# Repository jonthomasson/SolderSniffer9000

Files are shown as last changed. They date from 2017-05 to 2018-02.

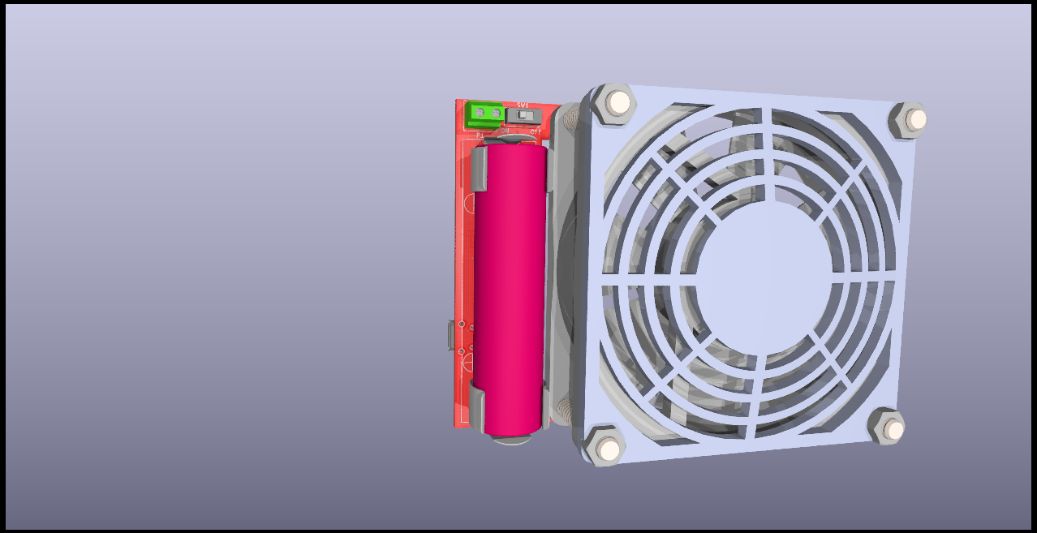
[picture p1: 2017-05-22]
rev1.a/SolderSniffer9000_3d_back.png

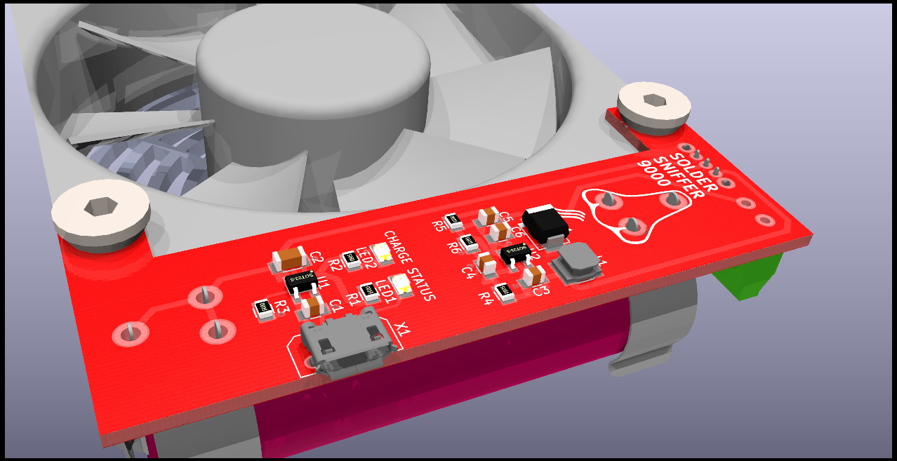
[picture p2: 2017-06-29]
rev1.a/SolderSniffer9000b.png

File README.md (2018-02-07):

# SolderSniffer9000
A DIY Solder Fume Extractor for 80mm Fan with built in battery charger.

It chops, it dices, it sucks, it blows, it's the Solder Sniffer 9000! After a recent move I was in need of a more portable solder fume extractor. Previously I was using a PC PSU hooked up to a small 80mm fan to suck away solder fumes. I thought it would be neat to make a portable sucker that could be recharged with the millions of micro USB cables I have lying around. Thus the Solder Sniffer 9000 was born! This project is built around an 80mm PSU fan. I chose this type and size fan because that's what I have laying around. I figured it'd be great if I could recycle some of these fans. The main PCB attaches to one side of the fan, via the fan mounting holes. For power I'm using a protected 18650 lithium cell. I'm using the Microchip MCP73831 charge controller to charge the battery via the Micro USB port. The battery is then boosted to the 12 volts required by the fan through use of the Semtech SC4503 step up regulator.
![enter image description here](https://lh3.googleusercontent.com/lAs5yyoZNqOFHvuRhlynxwo_R--8PWqJcgd_jjI6EHcwee4sk6s7vFg0BtDzGmjtqx0Ff0_K_e3mD94I6FwvLRuabP4b_9Osu1a5uzanZ7PESfyJPfpcDF5x4c6m_dsZqu9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)

![enter image description here](https://lh3.googleusercontent.com/34mNDDMhwQWCEcVDpiyjnw0Z-S3oCal-eQXqZIbWolDbLpy-xn97MdiaS-pX-pZ9BGYoCawT2w7hVak32vGW6cuKDikLCVMxaWiUwZszsmvlJUHRNDMsvFF96Da90ZJn-Jc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)

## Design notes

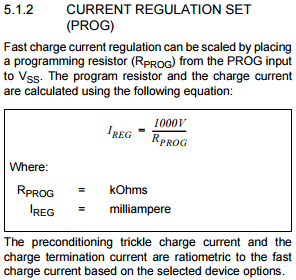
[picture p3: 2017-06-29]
rev1.a/mcp73831_currentreg.PNG

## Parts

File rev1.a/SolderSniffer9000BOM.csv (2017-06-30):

Digi-Key Part Number | Manufacturer | Manufacturer Part Number | Customer Reference | Quantity 1 | Quantity 2 | Quantity 3 | Mfg Std Lead Time | Description | Comments | RoHS Status | Lead Free Status | REACH Status
VS-10BQ015-M3/5BTGICT-ND | VISHAY SEMICONDUCTOR DIODES DIVISION (VA) | VS-10BQ015-M3/5BT | D1 | 1 | 0 | 0 | 11 Weeks | DIODE SCHOTTKY 15V 1A DO214AA | Alternate Packaging Exists | RoHS Compliant | Lead free | Unaffected Jan-2017
SC4503TSKCT-ND | SEMTECH CORPORATION (VA) | SC4503TSKTRT | U2 | 1 | 0 | 0 | 6 Weeks | IC REG BOOST ADJ 1.4A TSOT23-5 | Alternate Packaging Exists | RoHS Compliant | Lead free | Not Available
MCP73831T-2ACI/OTCT-ND | MICROCHIP TECHNOLOGY (VA) | MCP73831T-2ACI/OT | U1 | 1 | 0 | 0 | 6 Weeks | IC CONTROLLR LI-ION 4.2V SOT23-5 | Alternate Packaging Exists | RoHS Compliant | Lead free | Unaffected Jan-2017
SRN4018-2R7MCT-ND | BOURNS INC (VA) | SRN4018-2R7M | L1 | 1 | 0 | 0 | 28 Weeks | FIXED IND 2.7UH 2.3A 52 MOHM SMD | Alternate Packaging Exists | RoHS Compliant | Lead free | Unaffected Jan-2017
36-54-ND | KEYSTONE ELECTRONICS | 54 | BT1 | 2 | 0 | 0 | 6 Weeks | BATTERY CLIP 18MM 18650 CELL |  | RoHS Compliant | Lead free | Unaffected Jan-2017
ED2740-ND | ON SHORE TECHNOLOGY INC | OSTTE020104 | P1 | 1 | 0 | 0 | 10 Weeks | TERMINAL BLOCK 3.5MM 2POS PCB |  | RoHS Compliant | Lead free | Unaffected Jun-2016
CKN10397-ND | C&K | SS-12D07-VG 4 NS GA PA | SW1 | 1 | 0 | 0 | 6 Weeks | SWITCH SLIDE SPDT 300MA 30V |  | RoHS Compliant | Lead free | Unaffected Jan-2017
732-4984-1-ND | WURTH ELECTRONICS INC (VA) | 150080RS75000 | LED1 | 1 | 0 | 0 | 10 Weeks | LED RED CLEAR 0805 SMD | Alternate Packaging Exists | RoHS Compliant | Lead free | Unaffected Jun-2016
732-4986-1-ND | WURTH ELECTRONICS INC (VA) | 150080VS75000 | LED2 | 1 | 0 | 0 | 10 Weeks | LED GREEN CLEAR 0805 SMD | Alternate Packaging Exists | RoHS Compliant | Lead free | Unaffected Jun-2016
1276-2969-1-ND | SAMSUNG ELECTRO-MECHANICS AMERICA, INC (VA) | CL21B475KAFNNNE | C1, C6 | 2 | 0 | 0 | 12 Weeks | CAP CER 4.7UF 25V X7R 0805 | Alternate Packaging Exists | RoHS Compliant | Lead free | Unaffected Jan-2017
1276-1804-1-ND | SAMSUNG ELECTRO-MECHANICS AMERICA, INC (VA) | CL31B106KAHNNNE | C2 | 1 | 0 | 0 | 12 Weeks | CAP CER 10UF 25V X7R 1206 | Alternate Packaging Exists | RoHS Compliant | Lead free | Unaffected Jan-2017
1276-1162-1-ND | SAMSUNG ELECTRO-MECHANICS AMERICA, INC (VA) | CL21B225KOFNNNE | C3 | 1 | 0 | 0 | 12 Weeks | CAP CER 2.2UF 16V X7R 0805 | Alternate Packaging Exists | RoHS Compliant | Lead free | Unaffected Jan-2017
1276-1302-1-ND | SAMSUNG ELECTRO-MECHANICS AMERICA, INC (VA) | CL21C2R2CBANNNC | C5 | 1 | 0 | 0 | 12 Weeks | CAP CER 2.2PF 50V C0G/NP0 0805 | Alternate Packaging Exists | RoHS Compliant | Lead free | Unaffected Jan-2017
RMCF0805JT470RCT-ND | STACKPOLE ELECTRONICS INC (VA) | RMCF0805JT470R | R1, R2 | 2 | 0 | 0 | 12 Weeks | RES SMD 470 OHM 5% 1/8W 0805 | Alternate Packaging Exists | RoHS Compliant | Lead free | Unaffected Jan-2017
P2.00KCCT-ND | PANASONIC ELECTRONIC COMPONENTS (VA) | ERJ-6ENF2001V | R3 | 1 | 0 | 0 | 41 Weeks | RES SMD 2K OHM 1% 1/8W 0805 | Alternate Packaging Exists | RoHS Compliant | Lead free | Unaffected Jan-2017
311-15.0KCRCT-ND | YAGEO (VA) | RC0805FR-0715KL | R4 | 1 | 0 | 0 | 22 Weeks | RES SMD 15K OHM 1% 1/8W 0805 | Alternate Packaging Exists | RoHS Compliant | Lead free | Unaffected Jan-2017
311-866KCRCT-ND | YAGEO (VA) | RC0805FR-07866KL | R5 | 1 | 0 | 0 | 22 Weeks | RES SMD 866K OHM 1% 1/8W 0805 | Alternate Packaging Exists | RoHS Compliant | Lead free | Unaffected Jan-2017
311-100KCRCT-ND | YAGEO (VA) | RC0805FR-07100KL | R6 | 1 | 0 | 0 | 22 Weeks | RES SMD 100K OHM 1% 1/8W 0805 | Alternate Packaging Exists | RoHS Compliant | Lead free | Unaffected Jan-2017
1276-2536-1-ND | SAMSUNG ELECTRO-MECHANICS AMERICA, INC (VA) | CL21B563KBCNNNC | C4 | 1 | 0 | 0 | 12 Weeks | CAP CER 0.056UF 50V X7R 0805 | Alternate Packaging Exists | RoHS Compliant | Lead free | Unaffected Jan-2017
609-4618-1-ND | AMPHENOL FCI (VA) | 10118194-0001LF | X1 | 1 | 0 | 0 | 12 Weeks | CONN USB MICRO B RECPT SMT R/A | Alternate Packaging Exists | RoHS Compliant | Lead free | Not Available

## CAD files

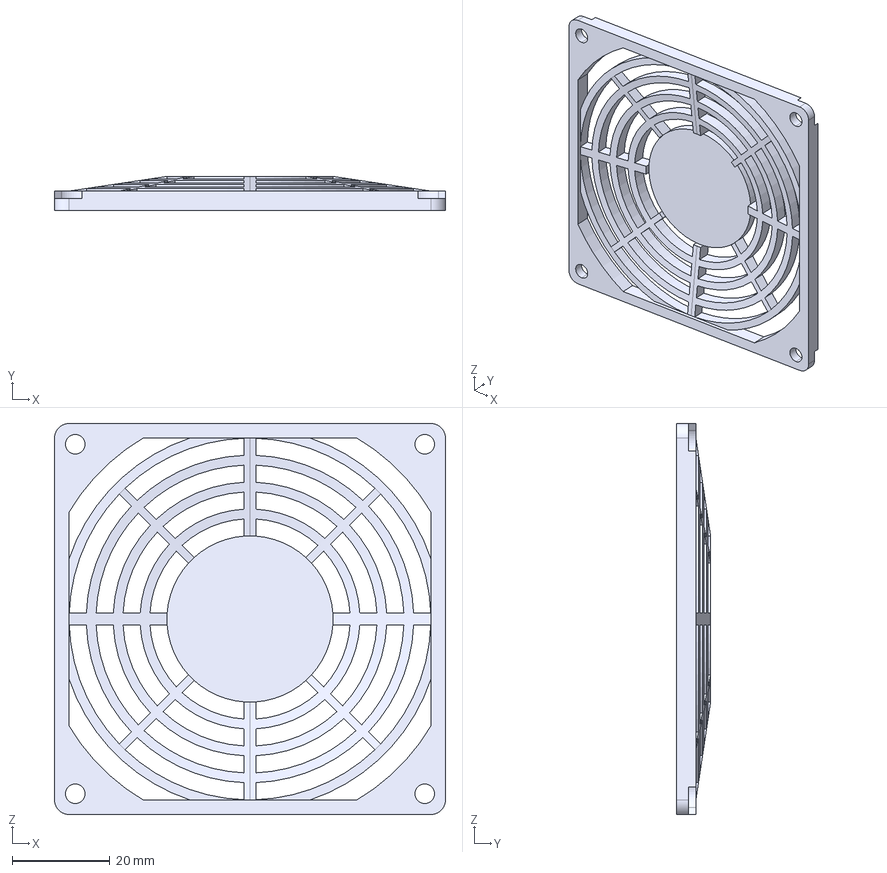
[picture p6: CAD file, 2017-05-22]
rev1.a/3dmodels/80MM_Fan_Filter.step
80.0 x 7.00 x 80.0 mm

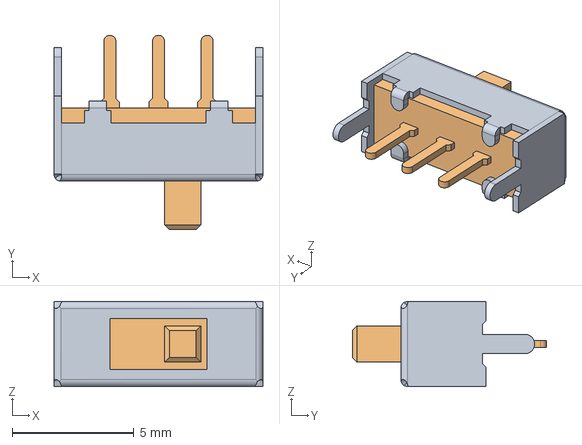
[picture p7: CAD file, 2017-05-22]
rev1.a/3dmodels/Switches_C&K_SS_12D07.step
8.60 x 8.00 x 3.50 mm

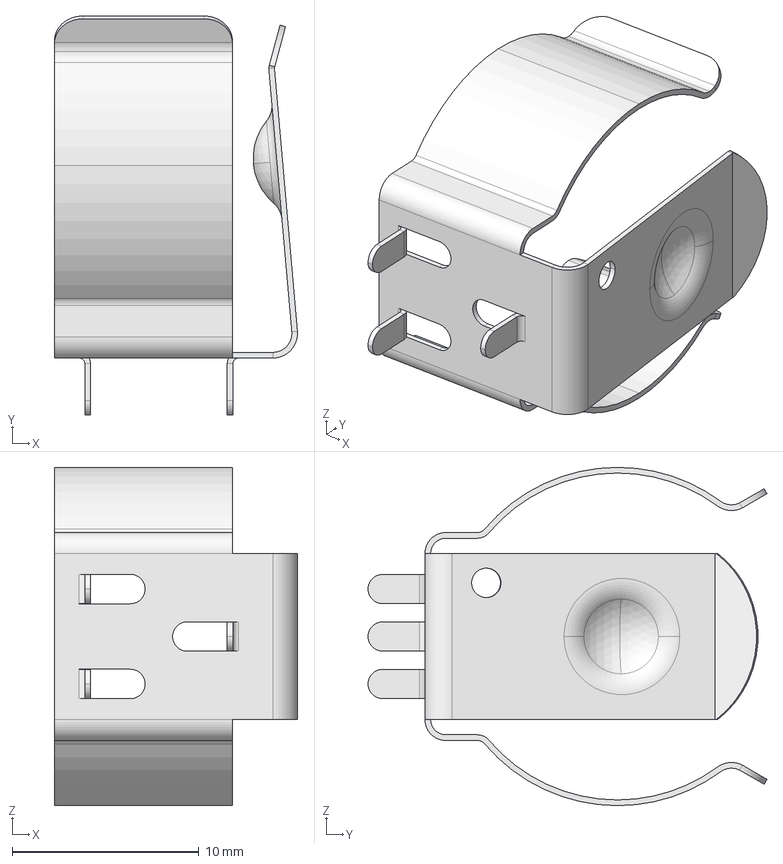
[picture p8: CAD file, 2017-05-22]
rev1.a/3dmodels/Batteries_Keystone_54.step
13.0 x 21.4 x 18.1 mm

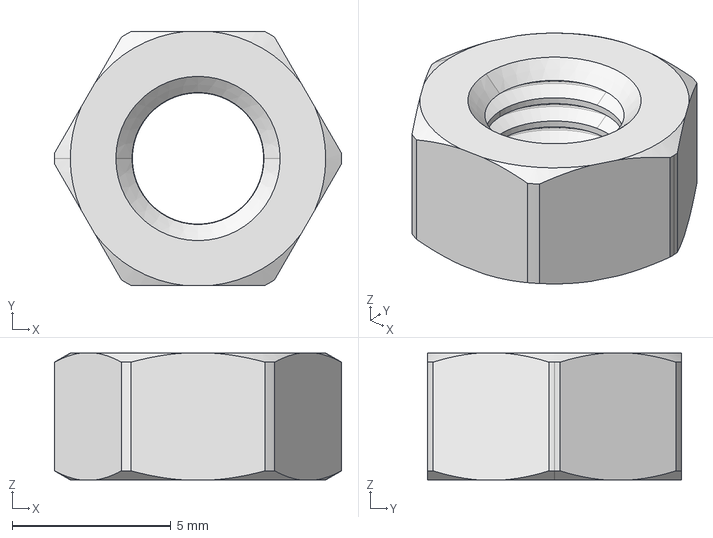
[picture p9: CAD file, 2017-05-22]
rev1.a/3dmodels/Nuts_M5.step
9.04 x 8.00 x 4.00 mm

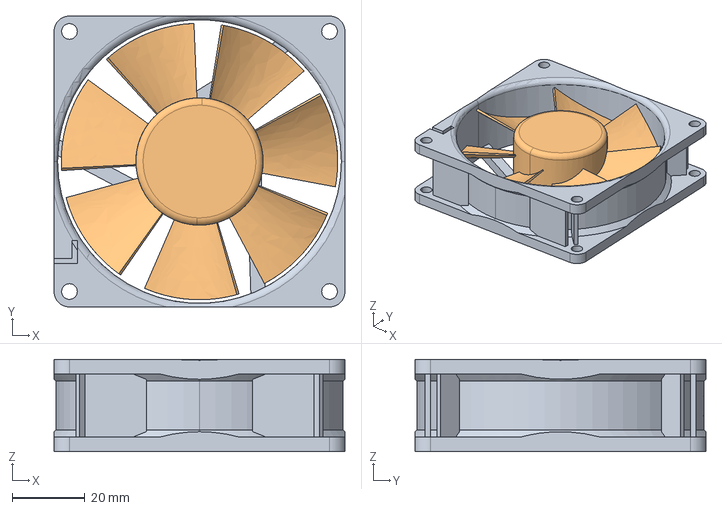
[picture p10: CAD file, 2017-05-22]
rev1.a/3dmodels/Motor_Fan.step
80.0 x 80.0 x 25.4 mm

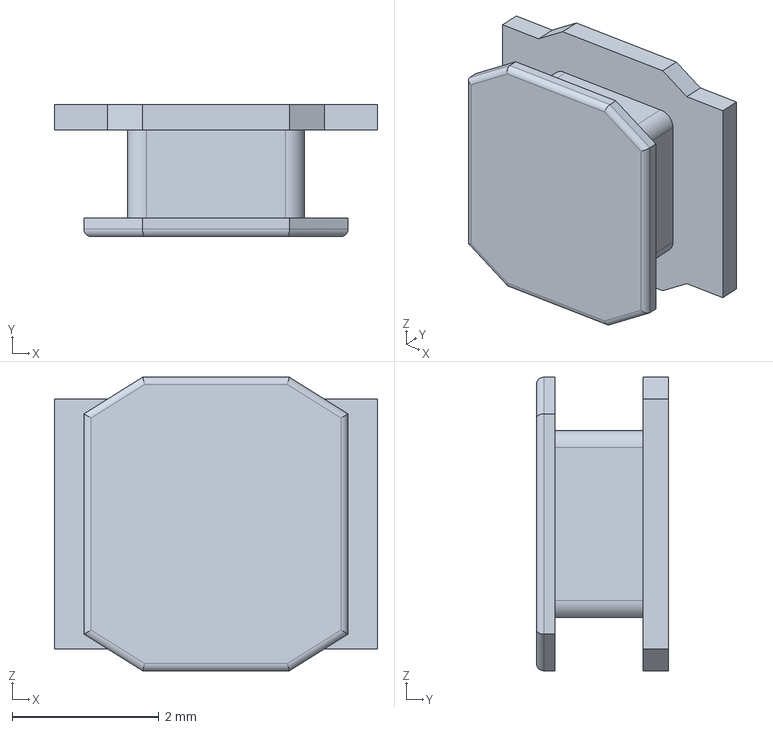
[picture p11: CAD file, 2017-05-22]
rev1.a/3dmodels/srn4018.stp
4.40 x 1.80 x 4.00 mm

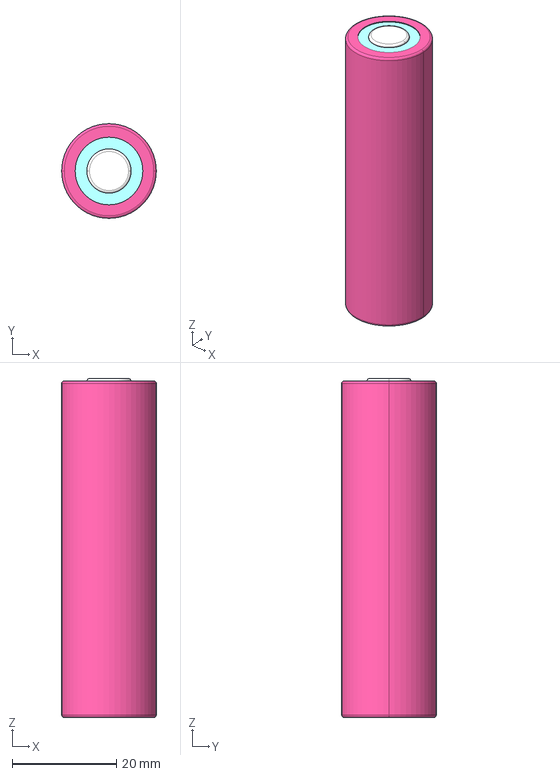
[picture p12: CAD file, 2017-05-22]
rev1.a/3dmodels/Battery_18650_c.step
18.2 x 18.2 x 65.2 mm

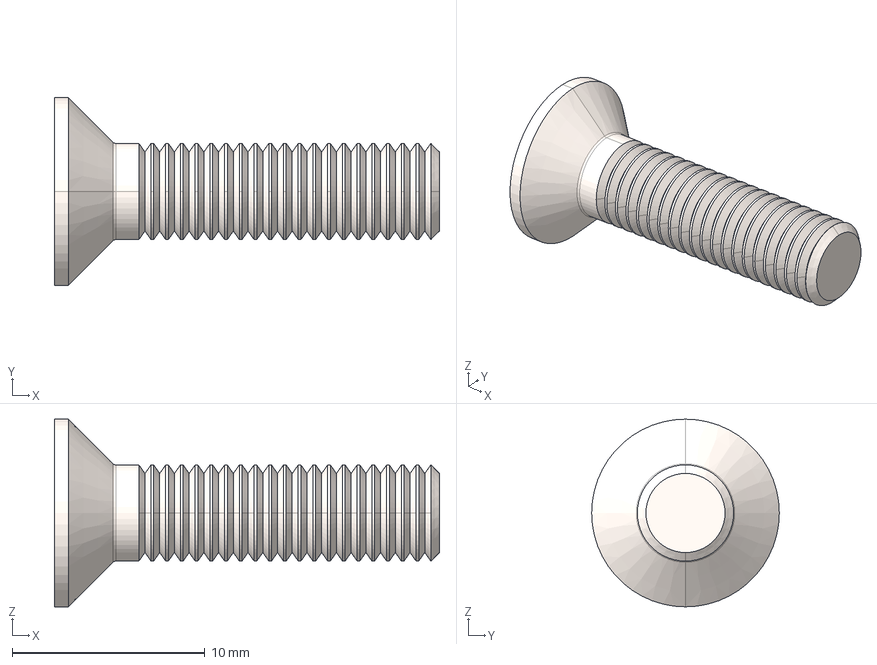
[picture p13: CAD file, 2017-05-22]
rev1.a/3dmodels/Screws_M5.step
20.0 x 9.75 x 9.75 mm

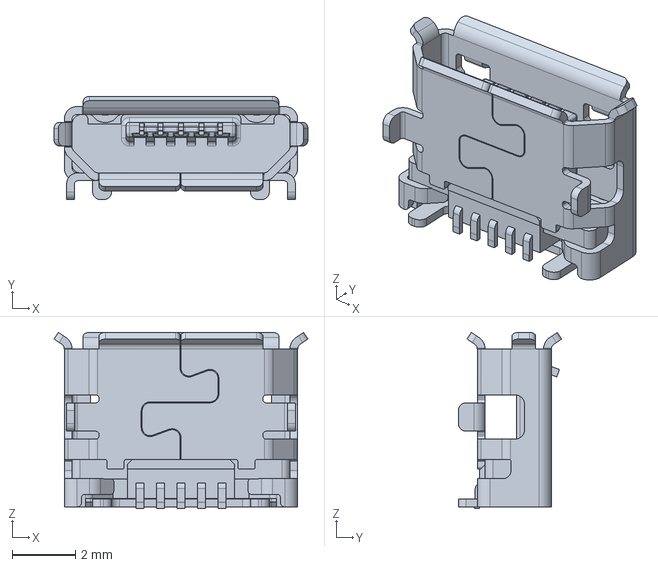
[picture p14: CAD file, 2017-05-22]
rev1.a/3dmodels/10118194c.stp
8.05 x 3.27 x 5.58 mm

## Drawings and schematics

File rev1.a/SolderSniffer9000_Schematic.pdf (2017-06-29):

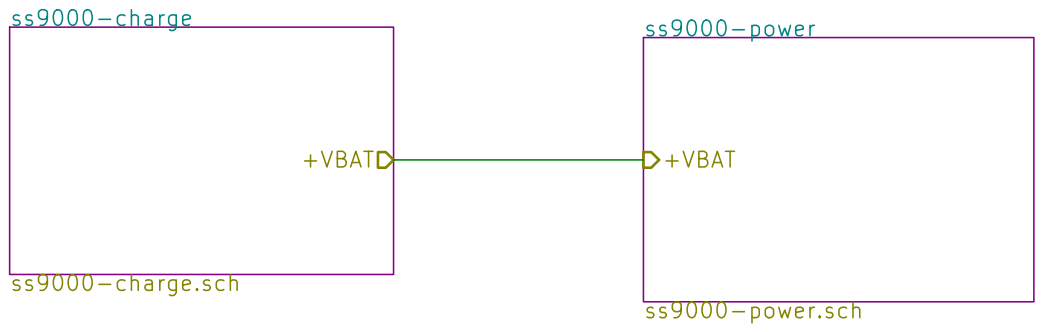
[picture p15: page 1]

Id: 1/3 Title: File: SolderSniffer9000.sch Sheet: /

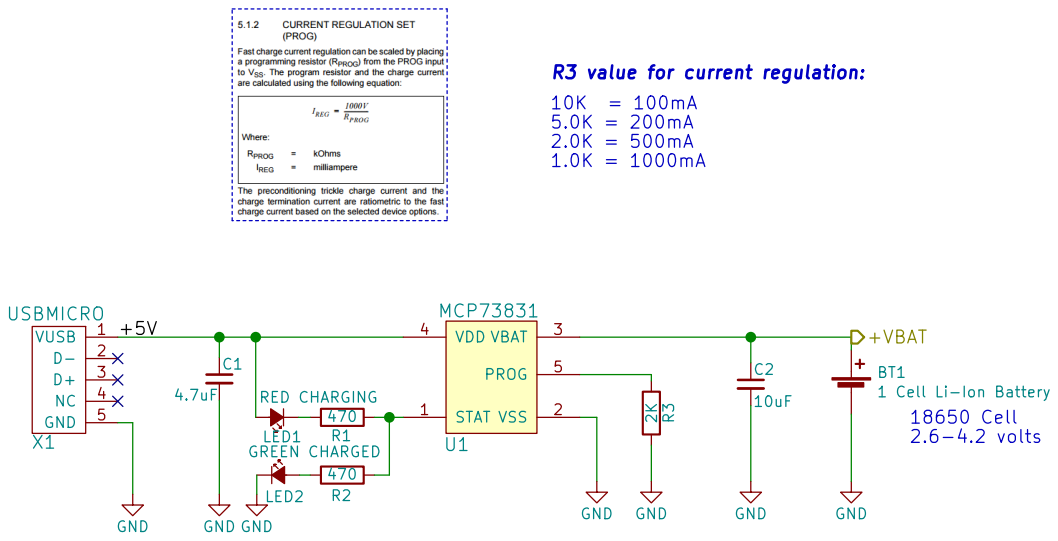
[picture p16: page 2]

1 Cell Li-Ion Battery GND

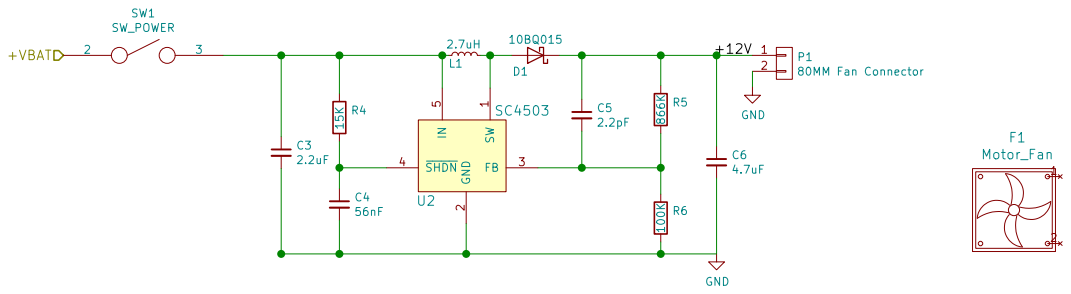
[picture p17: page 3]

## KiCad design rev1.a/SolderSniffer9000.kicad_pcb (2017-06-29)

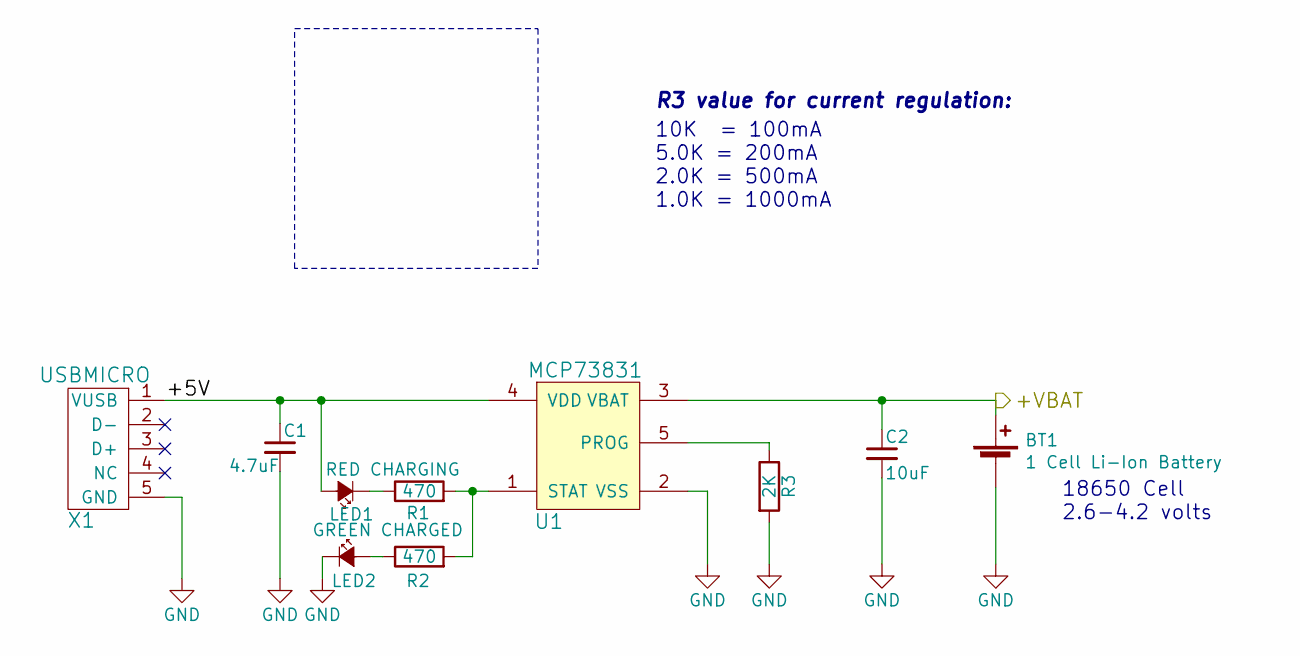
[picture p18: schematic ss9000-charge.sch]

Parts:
BT1: 1 Cell Li-Ion Battery; Batteries_Keystone_54
C1: 4.7uF; C_0805
C2: 10uF; C_1206
LED1: RED CHARGING; LED_0805
LED2: GREEN CHARGED; LED_0805
R1, R2: 470; R_0805
R3: 2K; R_0805
U1: MCP73831; Microchip_MCP73831
X1: USBMICRO; MICRO_USB_10118194

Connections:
/ss9000-charge/+5V: C1.1, LED1.2 (A), U1.4 (VDD), X1.1 (VUSB)
/ss9000-charge/+VBAT: BT1.1 (+), C2.1, U1.3 (VBAT); also elsewhere on the board
GND: BT1.2 (-), C1.2, C2.2, LED2.1 (K), R3.2, U1.2 (VSS), X1.5 (GND); also elsewhere on the board
unnamed: LED1.1 (K), R1.1
unnamed: LED2.2 (A), R2.1
unnamed: R1.2, R2.2, U1.1 (STAT)
unnamed: R3.1, U1.5 (PROG)

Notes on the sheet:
10K = 100mA 5.0K = 200mA 2.0K = 500mA 1.0K = 1000mA
18650 Cell 2.6-4.2 volts
R3 value for current regulation:

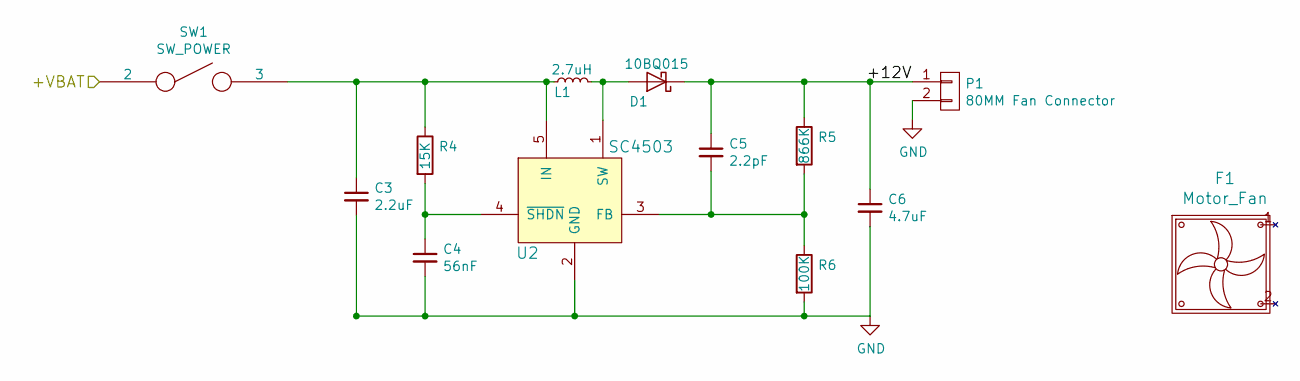
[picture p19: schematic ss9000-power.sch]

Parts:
C3: 2.2uF; C_0805
C4: 56nF; C_0805
C5: 2.2pF; C_0805
C6: 4.7uF; C_0805
D1: 10BQ015; do214aa
F1: Motor_Fan
L1: 2.7uH; Bourns_SRN4018_2R7M
P1: 80MM Fan Connector; Connector_OnShore_OSTTE020104
R4: 15K; R_0805
R5: 866K; R_0805
R6: 100K; R_0805
SW1: SW_POWER; Switches_C&K_SS12D07
U2: SC4503; SEMTECH-SC4503

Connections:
/ss9000-charge/+VBAT: SW1.2; also elsewhere on the board
/ss9000-power/+12V: C5.1, C6.1, D1.1 (K), P1.1, R5.1
GND: C3.2, C4.2, C6.2, P1.2, R6.2, U2.2 (GND); also elsewhere on the board
unnamed: C3.1, L1.1, R4.1, SW1.3, U2.5 (IN)
unnamed: C4.1, R4.2, U2.4 (~SHDN)
unnamed: C5.2, R5.2, R6.1, U2.3 (FB)
unnamed: D1.2 (A), L1.2, U2.1 (SW)

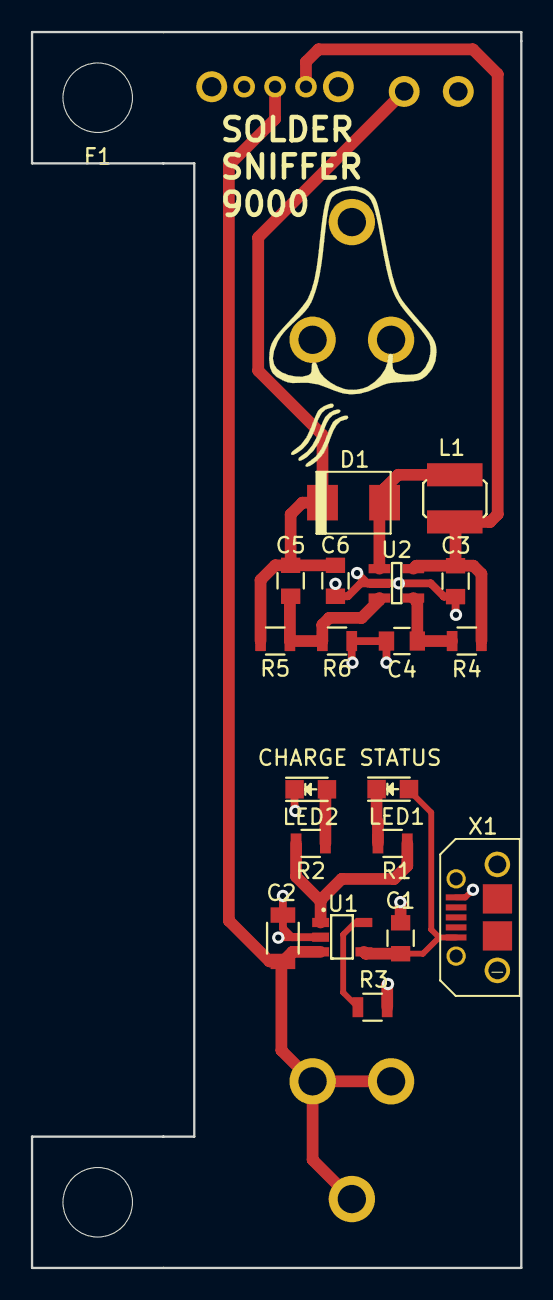
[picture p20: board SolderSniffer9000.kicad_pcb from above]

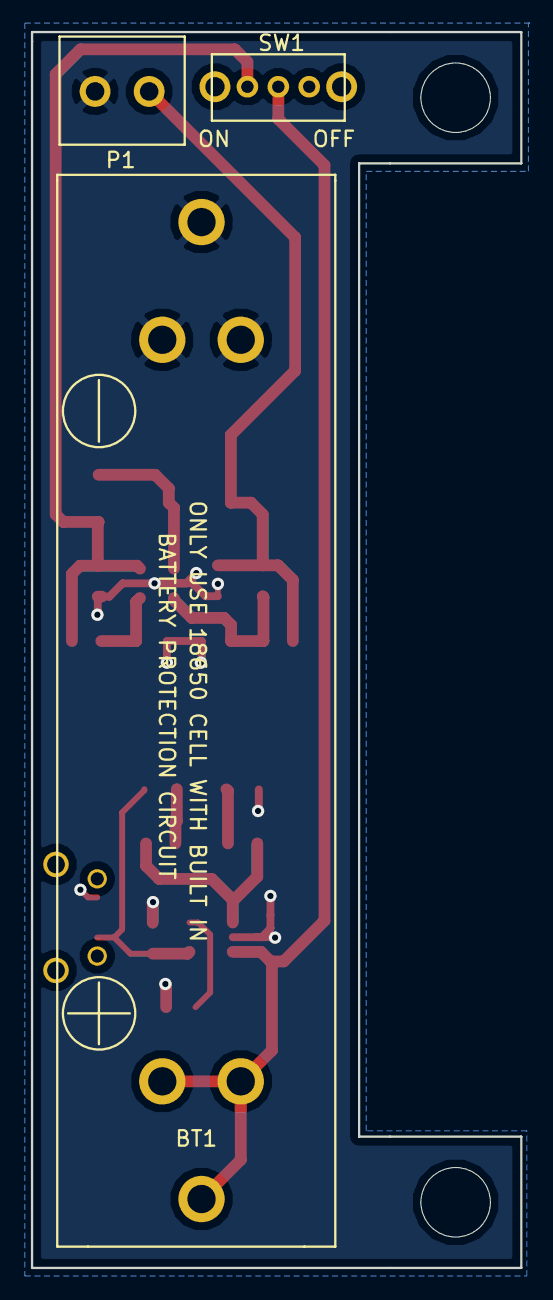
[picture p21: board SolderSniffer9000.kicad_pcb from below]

Board: 2 copper layers, 31.7 x 80.0 mm, 23 parts (3 on the bottom side), 12 nets.

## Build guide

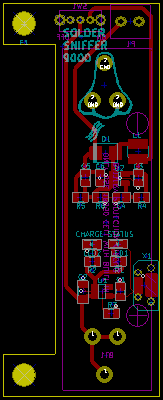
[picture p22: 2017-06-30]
rev1.a/SolderSniffer9000_pcb.PNG

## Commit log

2017-05-22 Initial Checkin
    [10118194c.stp, 80MM_Fan_Filter.step, Batteries_Keystone_54.step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]
2017-06-29 cosmetic changes to silk screen and updated schematic pdf
    [SolderSniffer9000.kicad_pcb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]
2017-06-30 updated pcb image
2017-06-30 added bom with digikey part list
    [SolderSniffer9000BOM.csv]
